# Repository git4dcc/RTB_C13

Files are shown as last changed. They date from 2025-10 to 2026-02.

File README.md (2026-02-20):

# RTB_C13





My homebrew RTB C13 track sensor features a 4 channel RailCom® detector, real-time block occupancy monitoring, and dedicated short-circuit protection. It also includes a built-in EDG bus interface, allowing for seamless accessory fan-out and expanded system integration.

<details>
<summary>See also</summary>

- [RTB_C10 - Master](/../../../../git4dcc/RTB_C10)
- [RTB_C11 - Power](/../../../../git4dcc/RTB_C11)
- [RTB_C12 - Booster](/../../../../git4dcc/RTB_C12)

</details>

<details>
<summary>User Guides</summary>

- User Guide - DE
- [User Guide - EN](https://rtb4dcc.de/rtb_user_guide_en/)

</details>

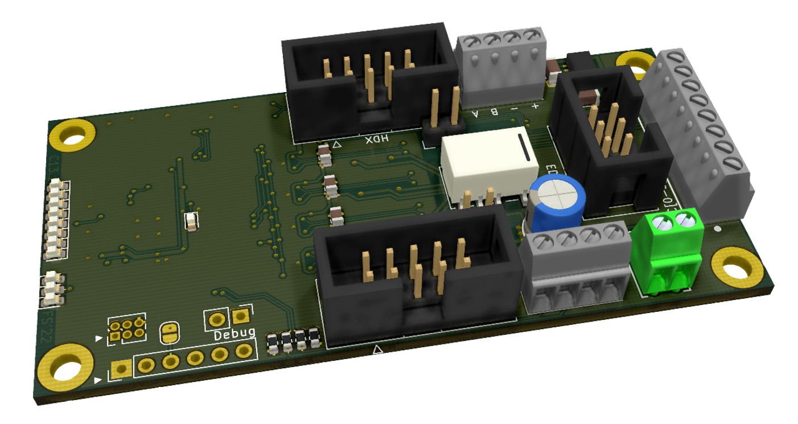
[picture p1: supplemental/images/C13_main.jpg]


## Track Sensor features
- **HDX**
  - HDX bus (2Mbps half duplex, RS-485 differential)
- **EDG**
  - EDG accessory bus bridge (2Mbps half duplex, TTL level)
- **DCC**
  - Quad-Channel Real-time RailCom® Monitoring and Block Occupancy detection.
  - Current measurement per channel
  - Short-circuit safeguarding for all 4 channels
- **Railcom Detector**
  - channel 1 / channel 2
  - detects unlimited number of decoder per track
  - real-time reporting
- **Current Sensor**
  - 1mA current sensitivity
- firmware update over the bus

# Hardware
The PCB layout uses SMD footprints with 0.4mm pitch, 0603 parts down to 0402. Reflow soldering is mandatory.
The PCB has been optimized for automated assembly (SMD parts are located on bottom side).

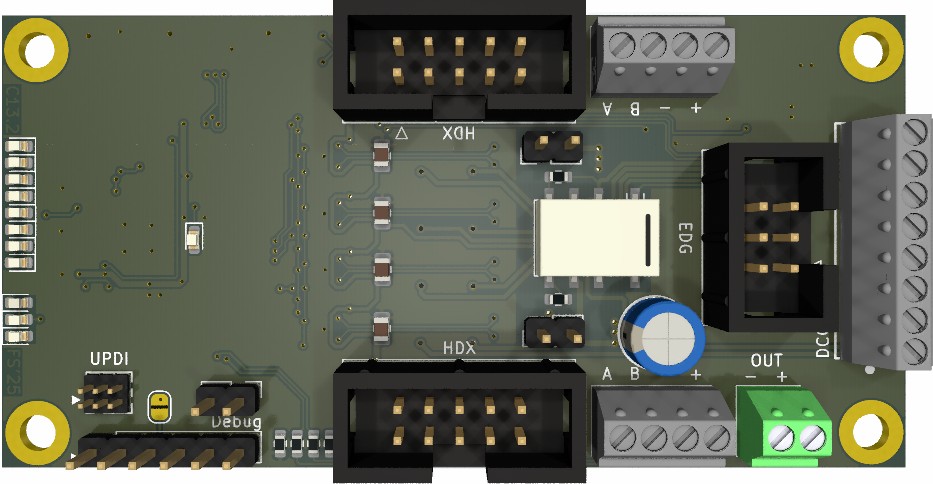
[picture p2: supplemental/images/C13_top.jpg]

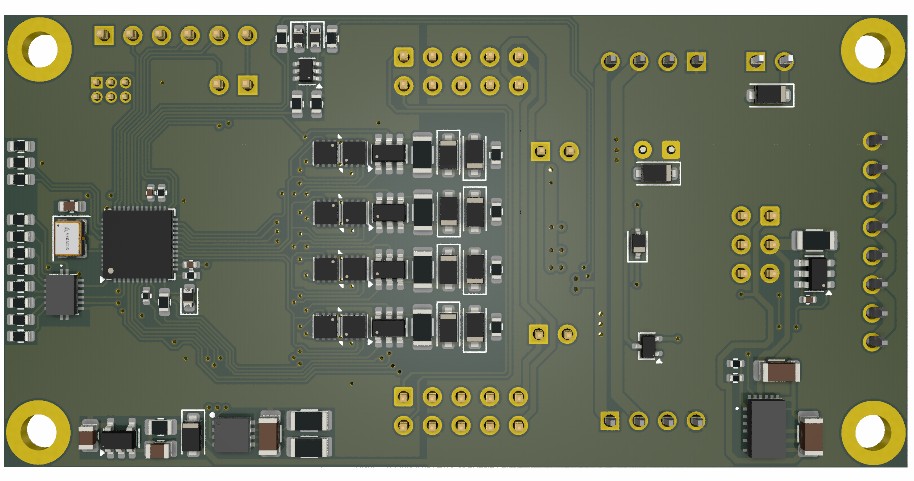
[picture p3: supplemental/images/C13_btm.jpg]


## PCB
- 2-layer PCB, FR4, 1.6mm
- CPU: AVR64DB48

## Kicad
[Schematic](doc/C13_schematic.pdf) | [Layout](doc/C13_layout.pdf) | [Gerber](gerber)

# Firmware
Filename structure: { **pcb** }{ **code** }{ **version** }.hex

Example: **C13F0001**.hex

| | Description |
| --- | --- |
| **pcb** | Name of matching hardware (**C13**) |
| **code** | Type of code contained (**R**=rom, **B**=bootloader, **F**=flash, **U**=bld update, **P**=UPDI factory code) |
| **version** | Release version (**####**) |

[Firmware files](firmware)

## UPDI / Fuses
The fuse settings as well as the P-code (C13Pxxxx.hex) has to be installed by using UPDI.<br>

| Fuses Setting |
| --- |
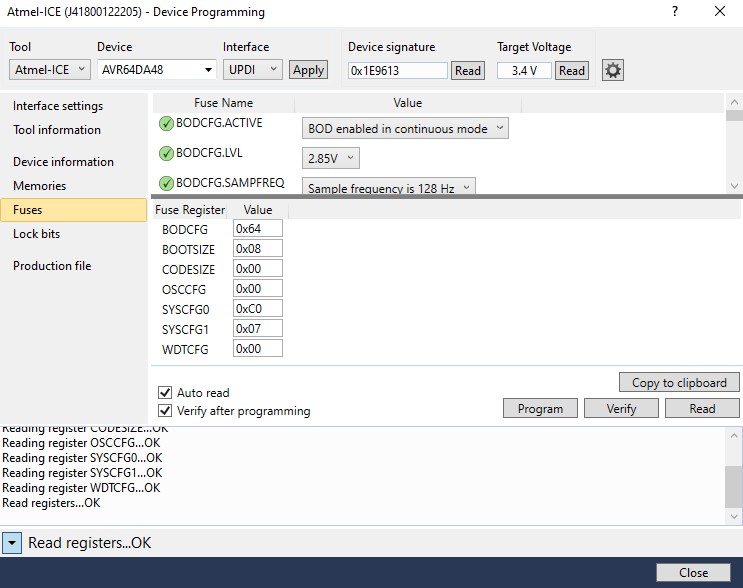
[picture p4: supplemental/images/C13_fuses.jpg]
||

# Images
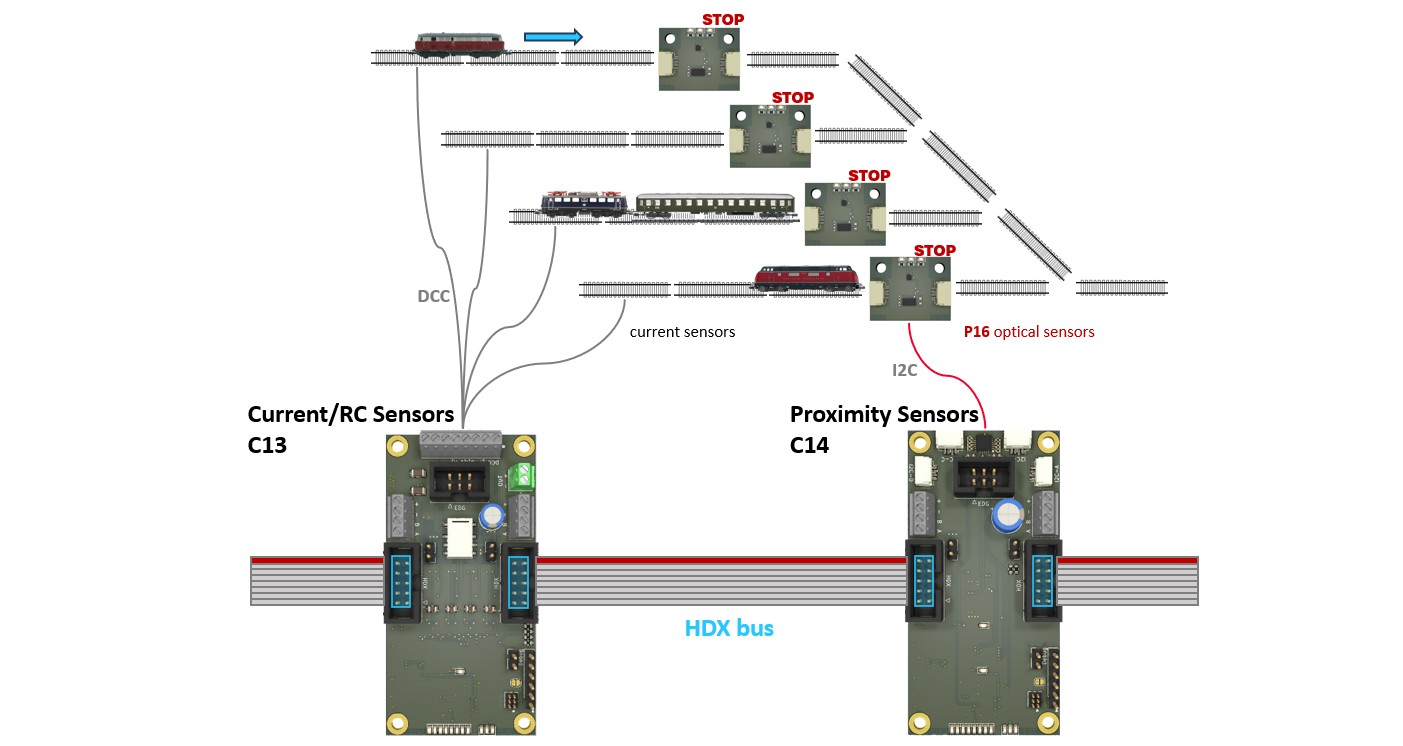
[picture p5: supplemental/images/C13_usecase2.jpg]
 

This project is intended for hobby use only and is distributed in accordance with the Apache License 2.0 agreement.

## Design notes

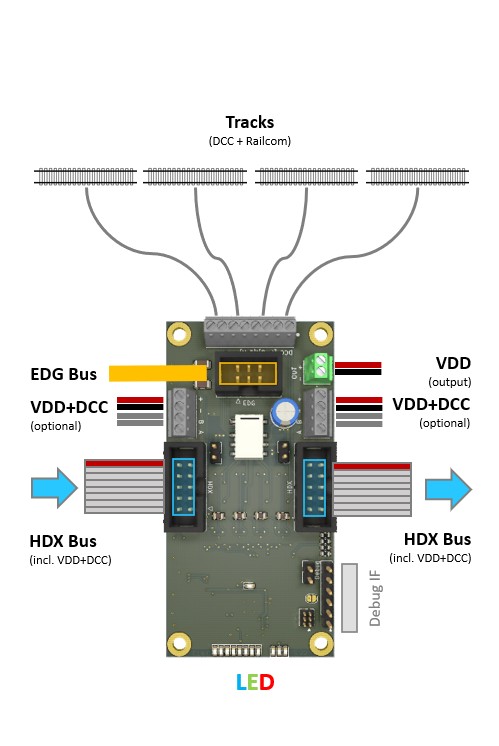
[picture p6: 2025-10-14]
supplemental/images/C13_usecase1.jpg

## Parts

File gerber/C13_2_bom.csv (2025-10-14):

Designator | Qty | Value | Exclude from BOM | Footprint | LCSC Part #
C.0.0,C.0.1 | 2 | FDX daisy chain | Excluded from BOM | Connector_IDC:IDC-Header_2x05_P2.54mm_Vertical
C5 | 1 | 100u/25V | Excluded from BOM | Capacitor_THT:CP_Radial_D6.3mm_P2.50mm
D2,D3 | 2 | LED(grn) | Excluded from BOM | LED_SMD:LED_0603_1608Metric
D5 | 1 | LED(blu) | Excluded from BOM | LED_SMD:LED_0603_1608Metric
D6 | 1 | LED(red) | Excluded from BOM | LED_SMD:LED_0603_1608Metric
D7,D8,D9,D10,D11,D12,D13,D14 | 8 | LED(wht) | Excluded from BOM | LED_SMD:LED_0603_1608Metric
H1,H2,H5,H7 | 4 | MountingHole | Excluded from BOM | MountingHole:MountingHole_3.2mm_M3_ISO7380_Pad
J1 | 1 | V24 | Excluded from BOM | Connector_PinHeader_2.54mm:PinHeader_1x06_P2.54mm_Vertical
J2 | 1 | DCC connector | Excluded from BOM | RTB:1725711
J3 | 1 | EDG connector | Excluded from BOM | Connector_IDC:IDC-Header_2x03_P2.54mm_Vertical
J4,J6 | 2 | Power Daisy Chain | Excluded from BOM | RTB:1725672
J5 | 1 | UDPI | Excluded from BOM | Connector_PinHeader_1.27mm:PinHeader_2x03_P1.27mm_Vertical
J7 | 1 | Power Output | Excluded from BOM | RTB:1725656
JP1 | 1 | SolderJumper_2_Open | Excluded from BOM | Jumper:SolderJumper-2_P1.3mm_Open_RoundedPad1.0x1.5mm
JP2,JP3,JP4 | 3 | Jumper_2_Open | Excluded from BOM | Connector_PinHeader_2.54mm:PinHeader_1x02_P2.54mm_Vertical
K1 | 1 | G6K-2 | Excluded from BOM | Relay_SMD:Relay_DPDT_Omron_G6K-2F-Y
U4 | 1 | 78M05 | Excluded from BOM | Package_TO_SOT_SMD:TO-252-2
C10 | 1 | 100n |  | Capacitor_SMD:C_0402_1005Metric | C1525
R31,R32 | 2 | 2.2k |  | Resistor_SMD:R_0603_1608Metric | C4190
R24,R26 | 2 | 1k |  | Resistor_SMD:R_0402_1005Metric | C11702
C7 | 1 | 22u/10V |  | Capacitor_SMD:C_1206_3216Metric | C12891
C8 | 1 | 10u/25V |  | Capacitor_SMD:C_1206_3216Metric | C13585
C11 | 1 | 100n |  | Capacitor_SMD:C_0603_1608Metric | C14663
R1 | 1 | 160 |  | Resistor_SMD:R_0805_2012Metric | C17471
R78,R79 | 2 | 100 |  | Resistor_SMD:R_1206_3216Metric | C17901
R20 | 1 | 160 |  | Resistor_SMD:R_0603_1608Metric | C22808
R34,R35 | 2 | 220k |  | Resistor_SMD:R_0603_1608Metric | C22961
R5,R6,R28,R72 | 4 | 3.3k |  | Resistor_SMD:R_0603_1608Metric | C22978
R9,R10,R11,R12,R13,R14,R15,R16 | 8 | 4.7k |  | Resistor_SMD:R_0603_1608Metric | C23162
R36,R37 | 2 | 9.1k |  | Resistor_SMD:R_0603_1608Metric | C23260
R3,R18,R21,R23,R27 | 5 | 22 |  | Resistor_SMD:R_0603_1608Metric | C23345
R30 | 1 | 13k |  | Resistor_SMD:R_0402_1005Metric | C25754
R7,R8 | 2 | 100k |  | Resistor_SMD:R_0603_1608Metric | C25803
R4 | 1 | 3.3k |  | Resistor_SMD:R_0402_1005Metric | C25890
C1,C2,C3,C4 | 4 | 1u |  | Capacitor_SMD:C_0805_2012Metric | C28323
R29 | 1 | 68k |  | Resistor_SMD:R_0402_1005Metric | C36871
C12 | 1 | 22u/6.3V |  | Capacitor_SMD:C_0805_2012Metric | C45783
C26 | 1 | 2.2u |  | Capacitor_SMD:C_1206_3216Metric | C50254
D1,D4,D15,D16,D17,D18,D19,D20,D21,D23,D24 | 11 | SS34FA |  | Diode_SMD:D_SOD-123F | C84632
U2 | 1 | MIC5235-3.3 |  | Package_TO_SOT_SMD:SOT-23-5 | C89886
D25,D30,D31 | 3 | Schottky |  | Diode_SMD:D_0603_1608Metric | C153761
Q3 | 1 | BC857BS |  | Package_TO_SOT_SMD:SOT-363_SC-70-6 | C156320
R2,R17,R19,R22 | 4 | 0.1 |  | Resistor_SMD:R_1206_3216Metric | C188071
D22 | 1 | D_Small |  | Diode_SMD:D_SOD-323 | C191023
C6,C13 | 2 | 100n |  | Capacitor_SMD:C_0402_1005Metric | C307331
R25 | 1 | 0.01 |  | Resistor_SMD:R_1206_3216Metric | C308574
C27 | 1 | 10u/25V |  | Capacitor_SMD:C_0805_2012Metric | C440198
U5,U6,U8,U9,U11,U12,U14,U15 | 8 | INA381 |  | Package_SON:WSON-8-1EP_2x2mm_P0.5mm_EP0.9x1.6mm | C544574
IC1 | 1 | 74HC595BQ,115 |  | 74HC595BQ115 | C547123
Q1 | 1 | BC848 |  | Package_TO_SOT_SMD:SOT-323_SC-70 | C600677
IC9 | 1 | THVD1450DRBR |  | RTB:SON65P300X300X100-9N-D | C1850226
X1 | 1 | ASE-xxxMHz |  | Oscillator:Oscillator_SMD_Abracon_ASE-4Pin_3.2x2.5mm | C1987527
U16 | 1 | INA181-A4 |  | Package_TO_SOT_SMD:SOT-23-6 | C2058842
U3,U7,U10,U13 | 4 | INA181-A1 |  | Package_TO_SOT_SMD:SOT-23-6 | C2058943
U1 | 1 | AVR-64DA48 |  | Package_DFN_QFN:UQFN-48-1EP_6x6mm_P0.4mm_EP4.62x4.62mm | C3227372
IC2 | 1 | MPM3610AGQV |  | RTB:MPM3610AGQVP | C5173872

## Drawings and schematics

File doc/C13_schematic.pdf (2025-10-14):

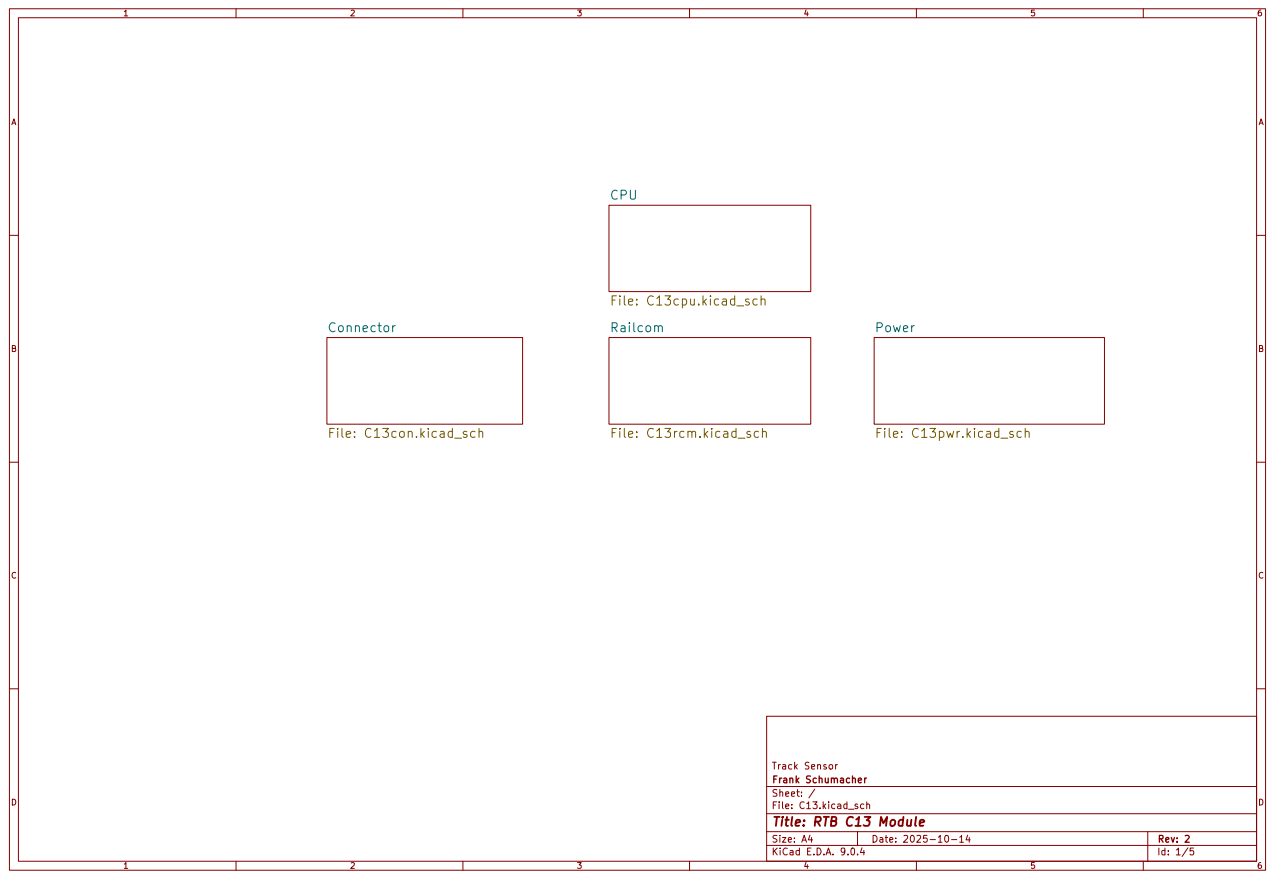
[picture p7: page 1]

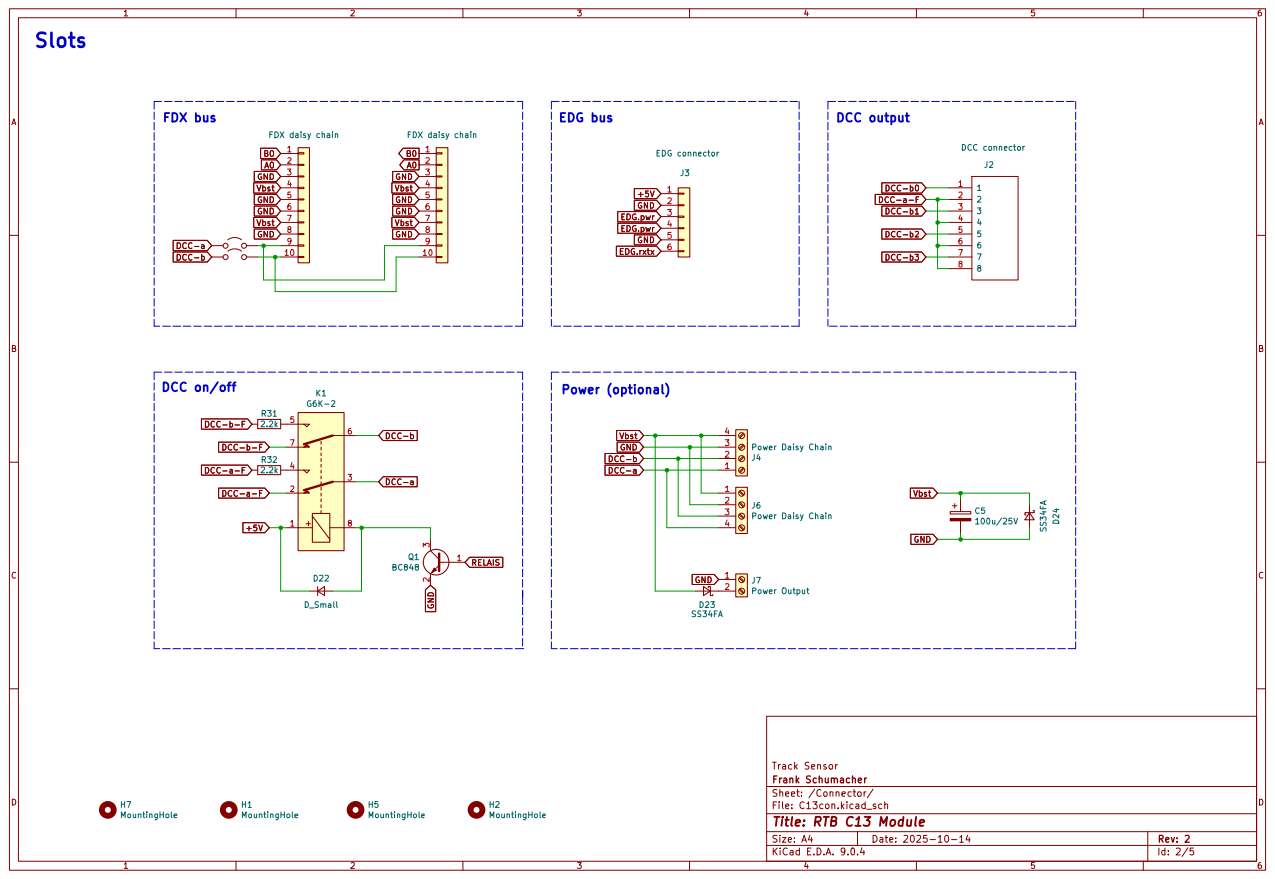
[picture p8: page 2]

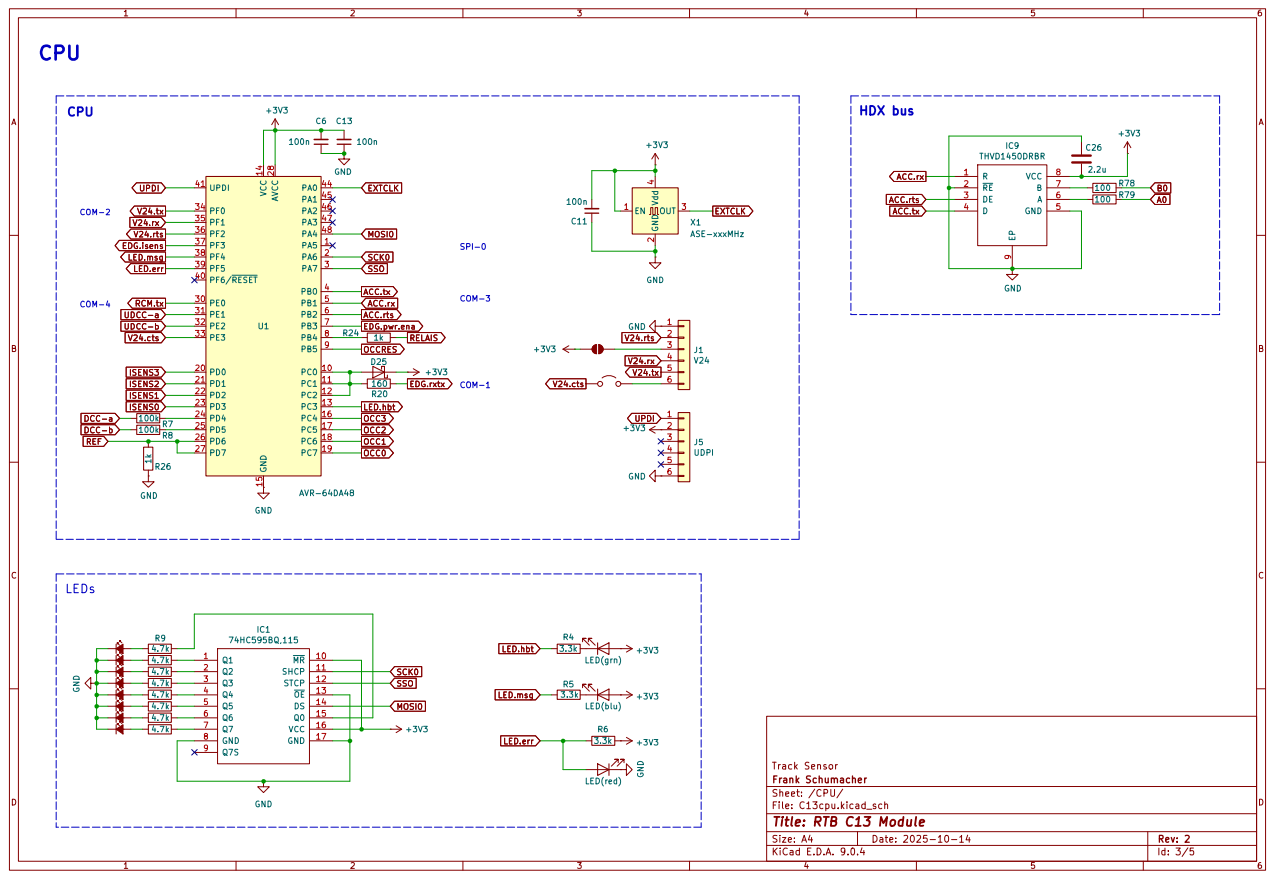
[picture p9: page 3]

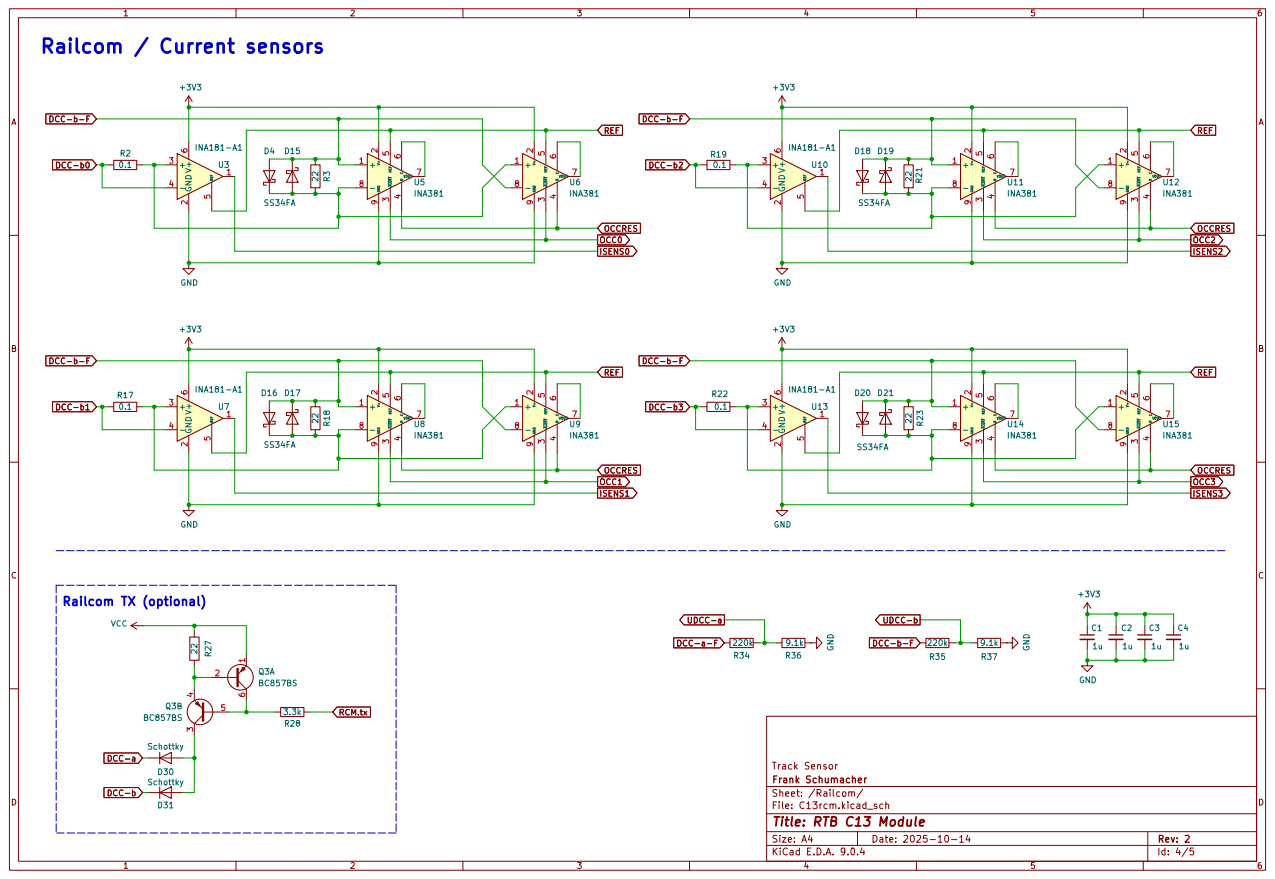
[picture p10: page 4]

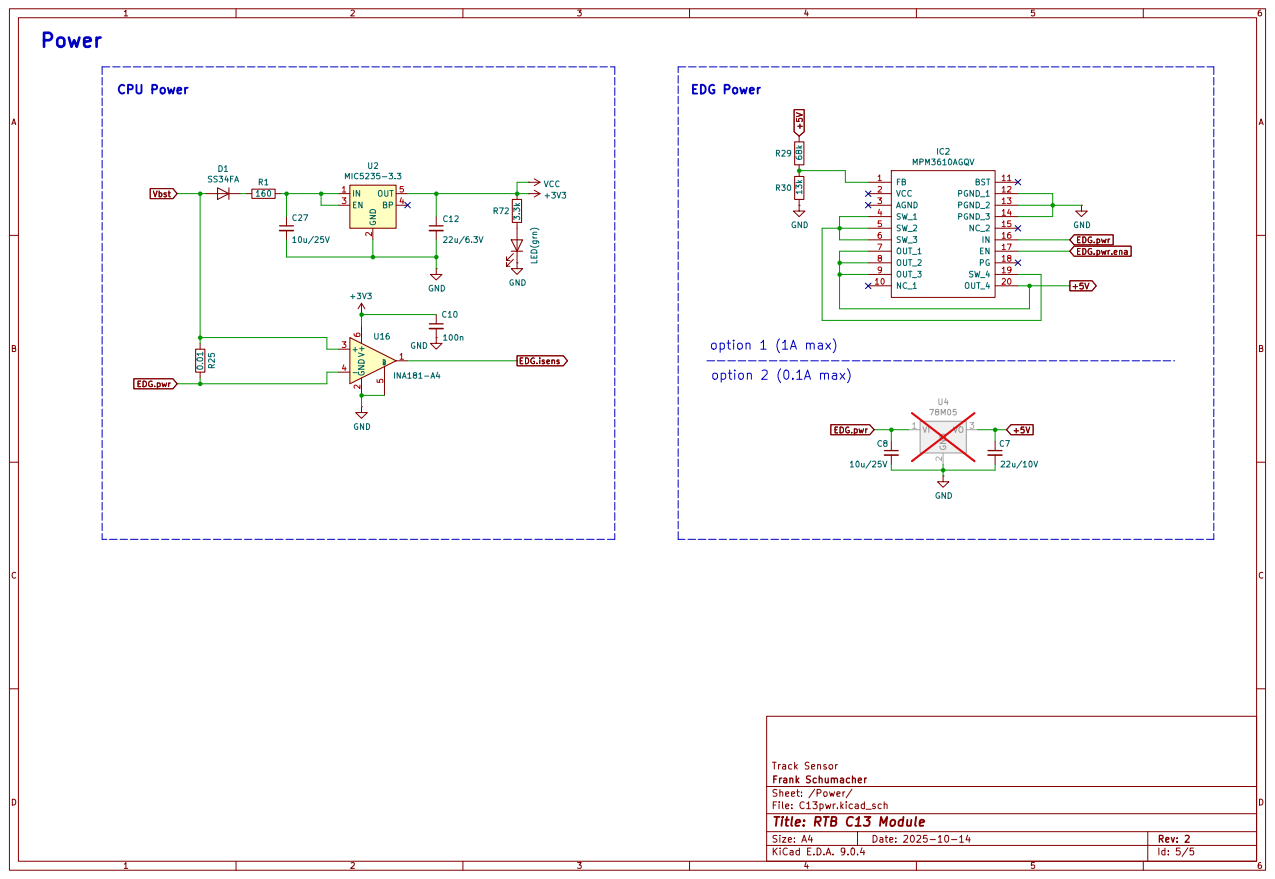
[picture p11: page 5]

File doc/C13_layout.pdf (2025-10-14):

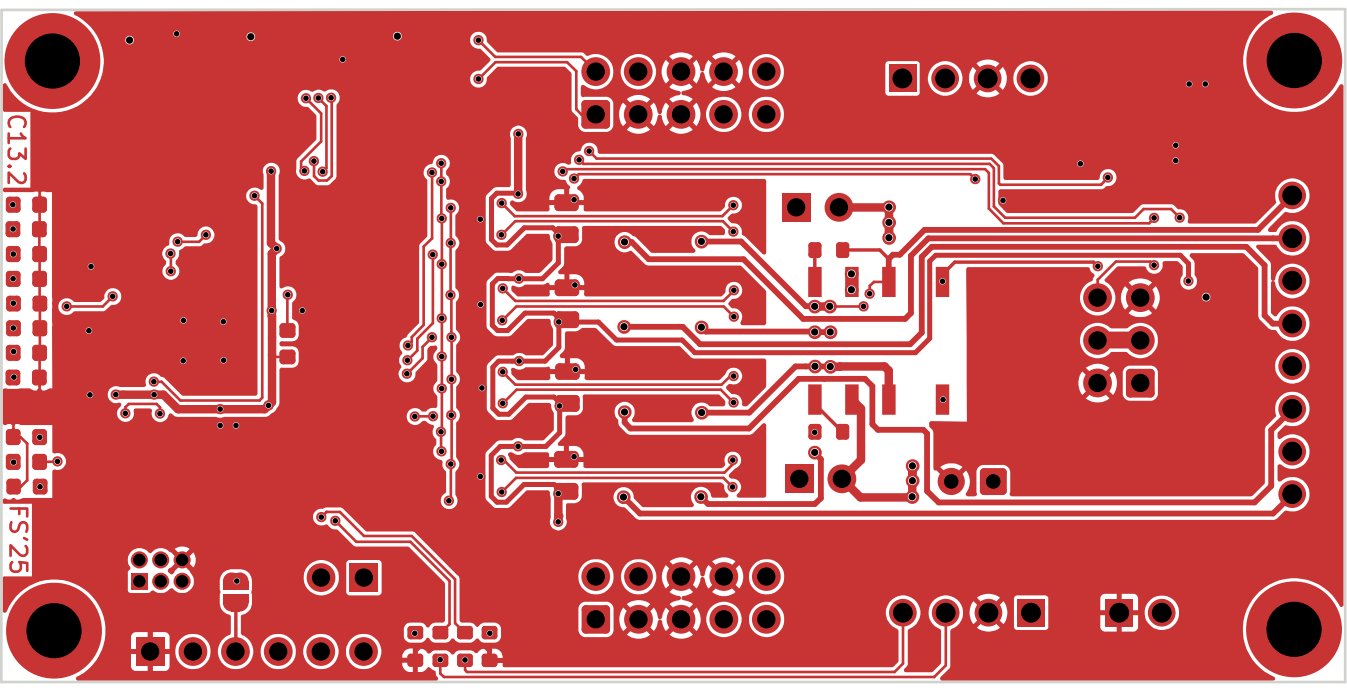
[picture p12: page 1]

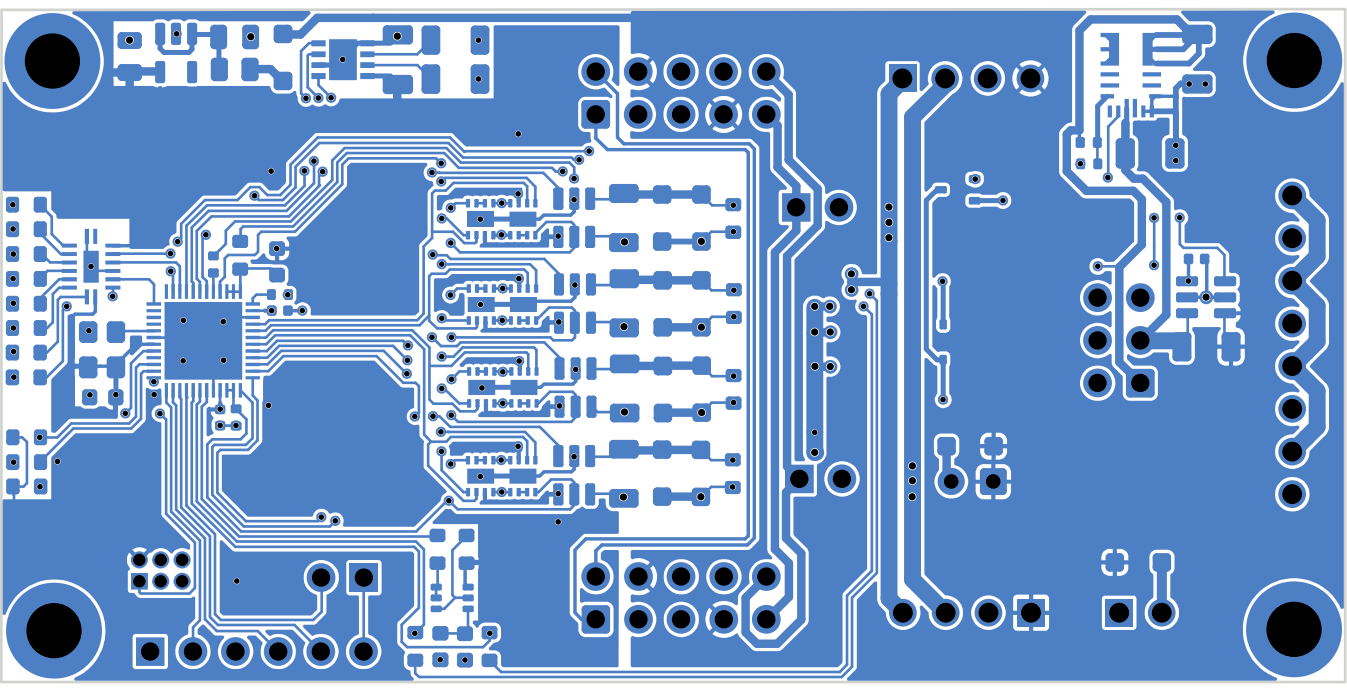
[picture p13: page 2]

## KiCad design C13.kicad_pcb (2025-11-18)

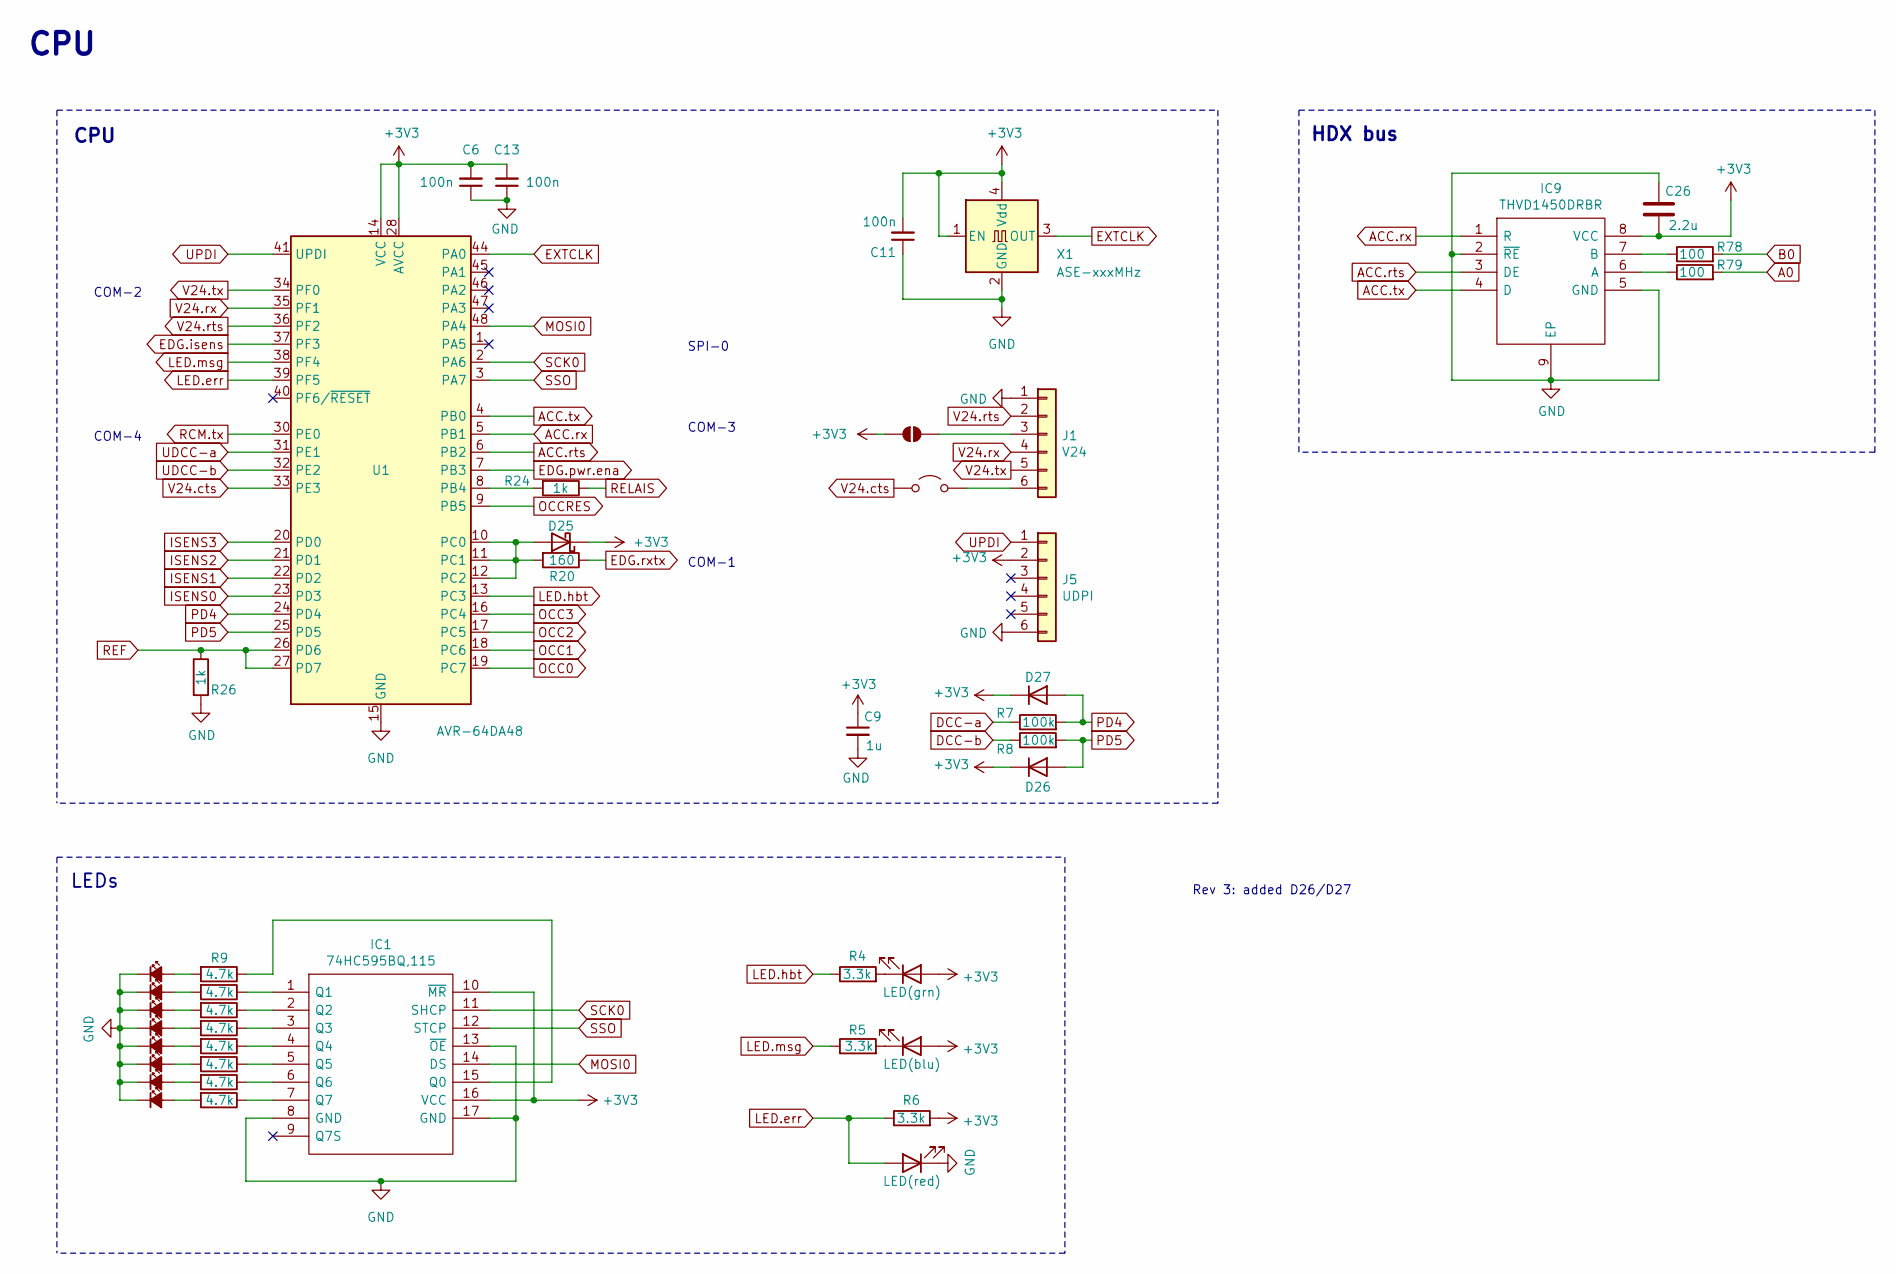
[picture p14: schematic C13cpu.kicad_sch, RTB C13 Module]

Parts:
C6, C13: 100n; C_0402_1005Metric; LCSC Part # C307331
C9: 1u; C_0805_2012Metric; LCSC Part # C28323
C11: 100n; C_0603_1608Metric; LCSC Part # C14663
C26: 2.2u; C_1206_3216Metric; LCSC Part # C50254
D3: LED(grn); LED_0603_1608Metric
D5: LED(blu); LED_0603_1608Metric
D6: LED(red); LED_0603_1608Metric
D7, D8, D9, D10, D11, D12, D13, D14: LED(wht); LED_0603_1608Metric
D25, D26, D27: Schottky; D_0603_1608Metric; LCSC Part # C153761
IC1: 74HC595BQ,115; 74HC595BQ115; Mouser Part Number 771-74HC595BQ-G; LCSC Part # C547123
IC9: THVD1450DRBR; SON65P300X300X100-9N-D; LCSC Part # C1850226
J1: V24; PinHeader_1x06_P2.54mm_Vertical
J5: UDPI; PinHeader_2x03_P1.27mm_Vertical
JP1: SolderJumper_2_Open; SolderJumper-2_P1.3mm_Open_RoundedPad1.0x1.5mm
JP2: Jumper_2_Open; PinHeader_1x02_P2.54mm_Vertical
R4: 3.3k; R_0402_1005Metric; LCSC Part # C25890
R5, R6: 3.3k; R_0603_1608Metric; LCSC Part # C22978
R7, R8: 100k; R_0603_1608Metric; LCSC Part # C25803
R9, R10, R11, R12, R13, R14, R15, R16: 4.7k; R_0603_1608Metric; LCSC Part # C23162
R20: 160; R_0603_1608Metric; LCSC Part # C22808
R24, R26: 1k; R_0402_1005Metric; LCSC Part # C11702
R78, R79: 100; R_1206_3216Metric; LCSC Part # C17901
U1: AVR-64DA48; UQFN-48-1EP_6x6mm_P0.4mm_EP4.62x4.62mm; LCSC Part # C3227372
X1: ASE-xxxMHz; Oscillator_SMD_Abracon_ASE-4Pin_3.2x2.5mm; LCSC Part # C1987527

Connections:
+3V3: C6.2, C9.1, C11.2, C13.2, C26.2, D3.2 (A), D5.2 (A), D25.1 (K), D26.1 (K), D27.1 (K), IC1.10 (~MR), IC1.16 (VCC), IC9.8 (VCC), J5.2, JP1.2 (B), R6.2, U1.14 (VCC), U1.28 (AVCC), U1.42 (VCC), X1.1 (EN), X1.4 (Vdd); also elsewhere on the board
A0: R79.2; also elsewhere on the board
ACC.rts: IC9.3 (DE), U1.6 (PB2)
ACC.rx: IC9.1 (R), U1.5 (PB1)
ACC.tx: IC9.4 (D), U1.4 (PB0)
B0: R78.2; also elsewhere on the board
DCC-a: R7.1; also elsewhere on the board
DCC-b: R8.1; also elsewhere on the board
EDG.isens: U1.37 (PF3); also elsewhere on the board
EDG.pwr.ena: U1.7 (PB3); also elsewhere on the board
EDG.rxtx: R20.1; also elsewhere on the board
EXTCLK: U1.44 (PA0), X1.3 (OUT)
GND: C6.1, C9.2, C11.1, C13.1, C26.1, D6.1 (K), D7.1 (K), D8.1 (K), D9.1 (K), D10.1 (K), D11.1 (K), D12.1 (K), D13.1 (K), D14.1 (K), IC1.8 (GND), IC1.13 (~OE), IC1.17 (GND), IC9.2 (~RE), IC9.5 (GND), IC9.9 (EP), J1.1, J5.6, R26.2, U1.15 (GND), U1.29 (GND), U1.43 (GND), U1.49 (GND), X1.2 (GND); also elsewhere on the board
ISENS0: U1.23 (PD3); also elsewhere on the board
ISENS1: U1.22 (PD2); also elsewhere on the board
ISENS2: U1.21 (PD1); also elsewhere on the board
ISENS3: U1.20 (PD0); also elsewhere on the board
LED.err: D6.2 (A), R6.1, U1.39 (PF5)
LED.hbt: R4.1, U1.13 (PC3)
LED.msg: R5.1, U1.38 (PF4)
MOSI0: IC1.14 (DS), U1.48 (PA4)
unnamed: D3.1 (K), R4.2
unnamed: D5.1 (K), R5.2
unnamed: D7.2 (A), R16.2
unnamed: D8.2 (A), R15.2
unnamed: D9.2 (A), R14.2
unnamed: D10.2 (A), R13.2
unnamed: D11.2 (A), R12.2
unnamed: D12.2 (A), R11.2
unnamed: D13.2 (A), R10.2
unnamed: D14.2 (A), R9.2
unnamed: D25.2 (A), R20.2, U1.10 (PC0), U1.11 (PC1), U1.12 (PC2)
unnamed: IC1.15 (Q0), R9.1
unnamed: IC1.1 (Q1), R10.1
unnamed: IC1.2 (Q2), R11.1
unnamed: IC1.3 (Q3), R12.1
unnamed: IC1.4 (Q4), R13.1
unnamed: IC1.5 (Q5), R14.1
unnamed: IC1.6 (Q6), R15.1
unnamed: IC1.7 (Q7), R16.1
unnamed: IC9.6 (A), R79.1
unnamed: IC9.7 (B), R78.1
unnamed: J1.3, JP1.1 (A)
unnamed: J1.6, JP2.1 (A)
unnamed: R24.2, U1.8 (PB4)
OCC0: U1.19 (PC7); also elsewhere on the board
OCC1: U1.18 (PC6); also elsewhere on the board
OCC2: U1.17 (PC5); also elsewhere on the board
OCC3: U1.16 (PC4); also elsewhere on the board
OCCRES: U1.9 (PB5); also elsewhere on the board
PD4: D27.2 (A), R7.2, U1.24 (PD4)
PD5: D26.2 (A), R8.2, U1.25 (PD5)
RCM.tx: U1.30 (PE0); also elsewhere on the board
REF: R26.1, U1.26 (PD6), U1.27 (PD7); also elsewhere on the board
RELAIS: R24.1; also elsewhere on the board
SCK0: IC1.11 (SHCP), U1.2 (PA6)
SSO: IC1.12 (STCP), U1.3 (PA7)
UDCC-a: U1.31 (PE1); also elsewhere on the board
UDCC-b: U1.32 (PE2); also elsewhere on the board
UPDI: J5.1, U1.41 (UPDI)
V24.cts: JP2.2 (B), U1.33 (PE3)
V24.rts: J1.2, U1.36 (PF2)
V24.rx: J1.4, U1.35 (PF1)
V24.tx: J1.5, U1.34 (PF0)

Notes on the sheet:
COM-4
COM-1
Rev 3: added D26/D27
COM-3
CPU
COM-2
LEDs
SPI-0
HDX bus

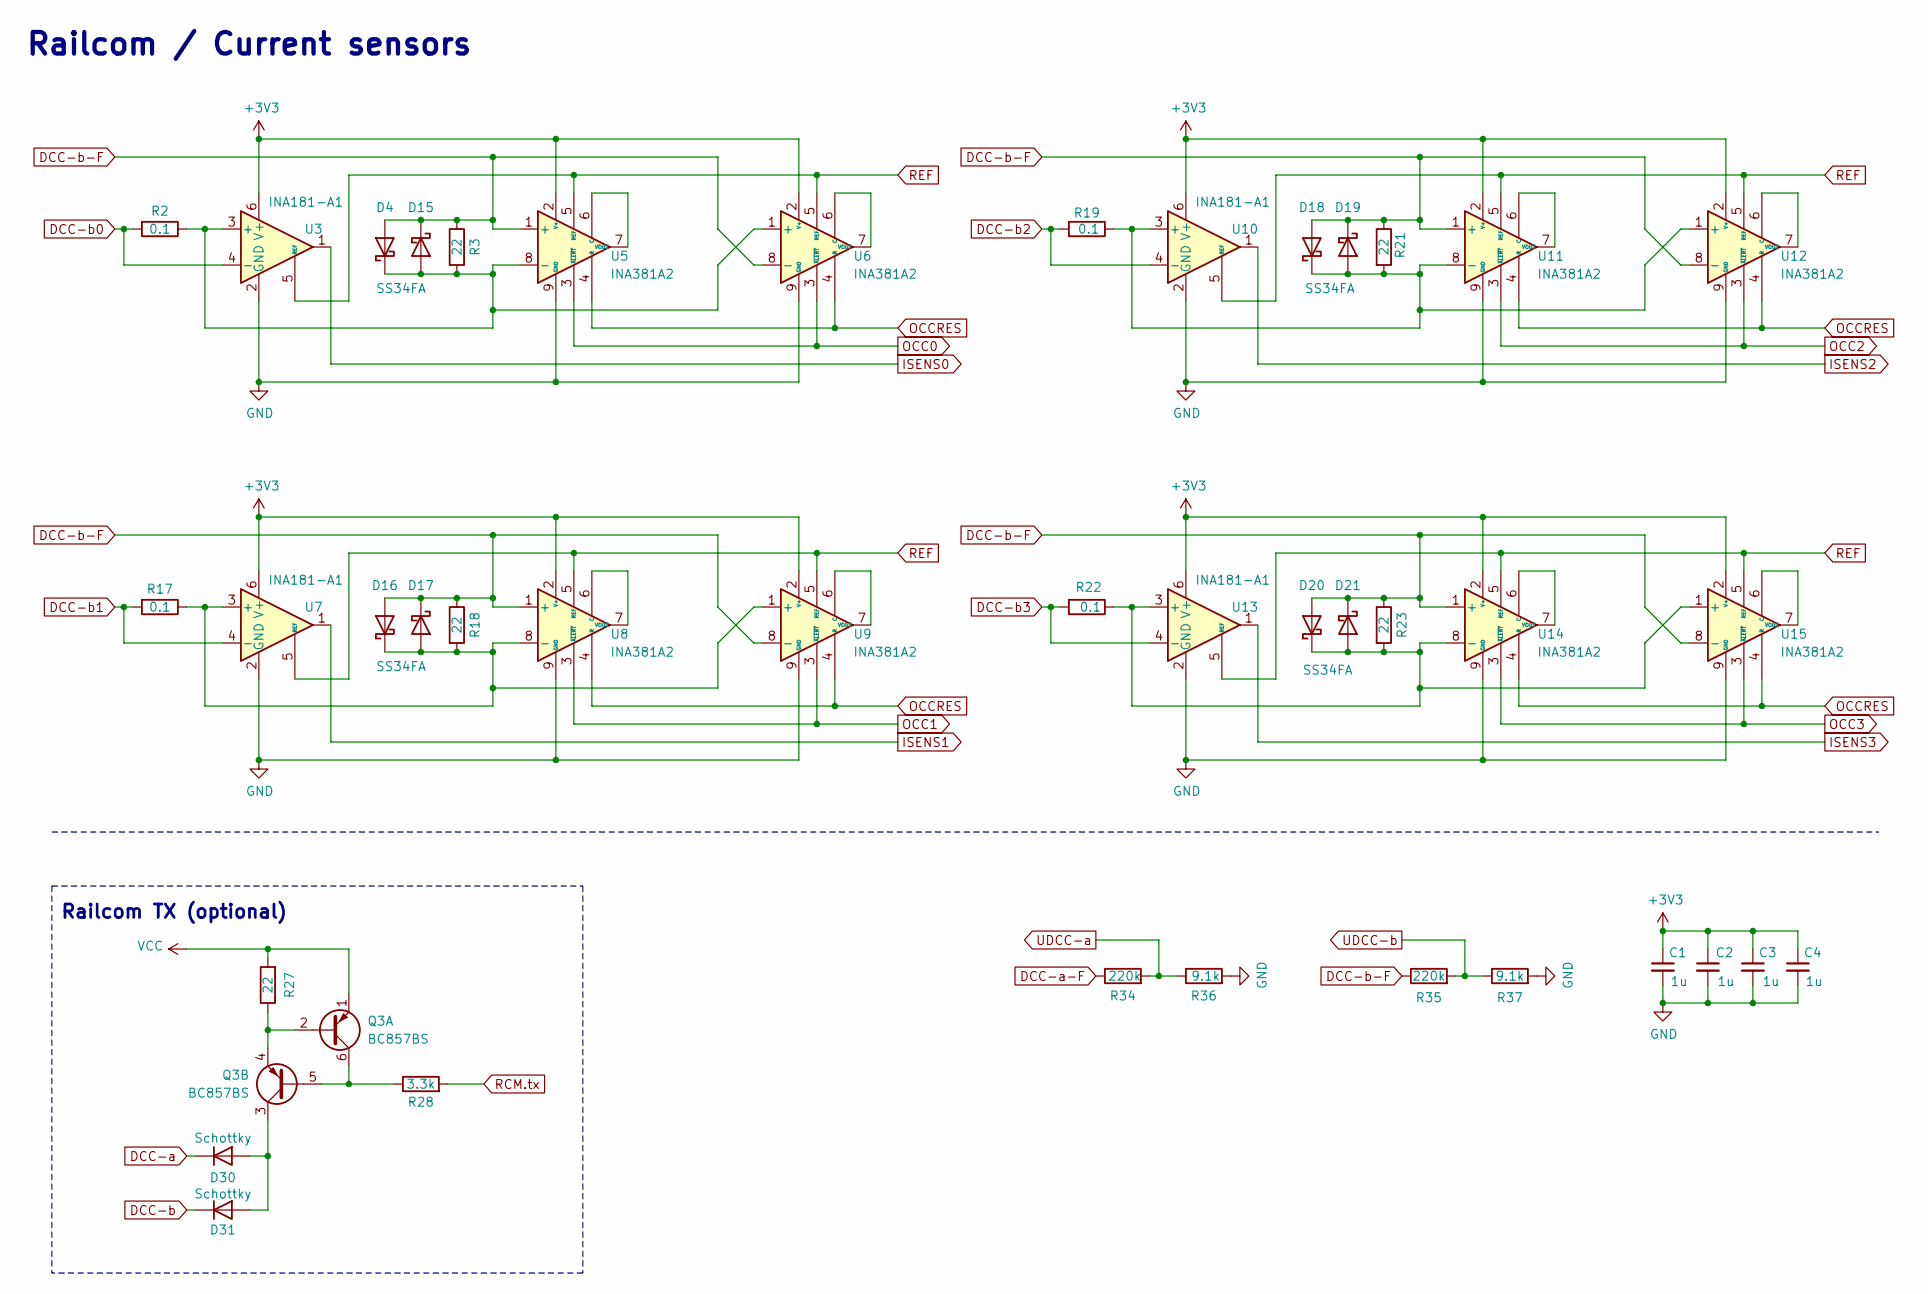
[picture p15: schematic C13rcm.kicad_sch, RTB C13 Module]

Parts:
C1, C2, C3, C4: 1u; C_0805_2012Metric; LCSC Part # C28323
D4, D15, D16, D17, D18, D19, D20, D21: SS34FA; D_SOD-123F; LCSC Part # C84632
D30, D31: Schottky; D_0603_1608Metric; LCSC Part # C153761
Q3: BC857BS; SOT-363_SC-70-6; LCSC Part # C156320
R2, R17, R19, R22: 0.1; R_1206_3216Metric; LCSC Part # C188071
R3, R18, R21, R23, R27: 22; R_0603_1608Metric; LCSC Part # C23345
R28: 3.3k; R_0603_1608Metric; LCSC Part # C22978
R34, R35: 220k; R_0603_1608Metric; LCSC Part # C22961
R36, R37: 9.1k; R_0603_1608Metric; LCSC Part # C23260
U3, U7, U10, U13: INA181-A1; SOT-23-6; LCSC Part # C2058943
U5, U6, U8, U9, U11, U12, U14, U15: INA381A2; WSON-8-1EP_2x2mm_P0.5mm_EP0.9x1.6mm; LCSC Part # C2155688

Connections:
+3V3: C1.1, C2.1, C3.1, C4.1, Q3.1 (E1), R27.2, U3.6 (V+), U5.2 (V+), U6.2 (V+), U7.6 (V+), U8.2 (V+), U9.2 (V+), U10.6 (V+), U11.2 (V+), U12.2 (V+), U13.6 (V+), U14.2 (V+), U15.2 (V+); also elsewhere on the board
DCC-a: D30.1 (K); also elsewhere on the board
DCC-a-F: R34.1; also elsewhere on the board
DCC-b: D31.1 (K); also elsewhere on the board
DCC-b0: R2.2, U3.4 (-); also elsewhere on the board
DCC-b1: R17.2, U7.4 (-); also elsewhere on the board
DCC-b2: R19.2, U10.4 (-); also elsewhere on the board
DCC-b3: R22.2, U13.4 (-); also elsewhere on the board
DCC-b-F: D4.2 (A), D15.1 (K), D16.2 (A), D17.1 (K), D18.2 (A), D19.1 (K), D20.2 (A), D21.1 (K), R3.1, R18.1, R21.1, R23.1, R35.1, U5.1 (+), U6.8 (-), U8.1 (+), U9.8 (-), U11.1 (+), U12.8 (-), U14.1 (+), U15.8 (-); also elsewhere on the board
GND: C1.2, C2.2, C3.2, C4.2, R36.2, R37.2, U3.2 (GND), U5.9 (GND), U6.9 (GND), U7.2 (GND), U8.9 (GND), U9.9 (GND), U10.2 (GND), U11.9 (GND), U12.9 (GND), U13.2 (GND), U14.9 (GND), U15.9 (GND); also elsewhere on the board
ISENS0: U3.1; also elsewhere on the board
ISENS1: U7.1; also elsewhere on the board
ISENS2: U10.1; also elsewhere on the board
ISENS3: U13.1; also elsewhere on the board
unnamed: D4.1 (K), D15.2 (A), R2.1, R3.2, U3.3 (+), U5.8 (-), U6.1 (+)
unnamed: D16.1 (K), D17.2 (A), R17.1, R18.2, U7.3 (+), U8.8 (-), U9.1 (+)
unnamed: D18.1 (K), D19.2 (A), R19.1, R21.2, U10.3 (+), U11.8 (-), U12.1 (+)
unnamed: D20.1 (K), D21.2 (A), R22.1, R23.2, U13.3 (+), U14.8 (-), U15.1 (+)
unnamed: D30.2 (A), D31.2 (A), Q3.3 (C2)
unnamed: Q3.2 (B1), Q3.4 (E2), R27.1
unnamed: Q3.5 (B2), Q3.6 (C1), R28.1
unnamed: U5.6 (C), U5.7 (VOUT)
unnamed: U6.6 (C), U6.7 (VOUT)
unnamed: U8.6 (C), U8.7 (VOUT)
unnamed: U9.6 (C), U9.7 (VOUT)
unnamed: U11.6 (C), U11.7 (VOUT)
unnamed: U12.6 (C), U12.7 (VOUT)
unnamed: U14.6 (C), U14.7 (VOUT)
unnamed: U15.6 (C), U15.7 (VOUT)
OCC0: U5.3 (~ALERT), U6.3 (~ALERT); also elsewhere on the board
OCC1: U8.3 (~ALERT), U9.3 (~ALERT); also elsewhere on the board
OCC2: U11.3 (~ALERT), U12.3 (~ALERT); also elsewhere on the board
OCC3: U14.3 (~ALERT), U15.3 (~ALERT); also elsewhere on the board
OCCRES: U5.4 (R), U6.4 (R), U8.4 (R), U9.4 (R), U11.4 (R), U12.4 (R), U14.4 (R), U15.4 (R); also elsewhere on the board
RCM.tx: R28.2; also elsewhere on the board
REF: U3.5 (REF), U5.5 (REF), U6.5 (REF), U7.5 (REF), U8.5 (REF), U9.5 (REF), U10.5 (REF), U11.5 (REF), U12.5 (REF), U13.5 (REF), U14.5 (REF), U15.5 (REF); also elsewhere on the board
UDCC-a: R34.2, R36.1; also elsewhere on the board
UDCC-b: R35.2, R37.1; also elsewhere on the board

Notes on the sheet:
Railcom / Current sensors
Railcom TX (optional)

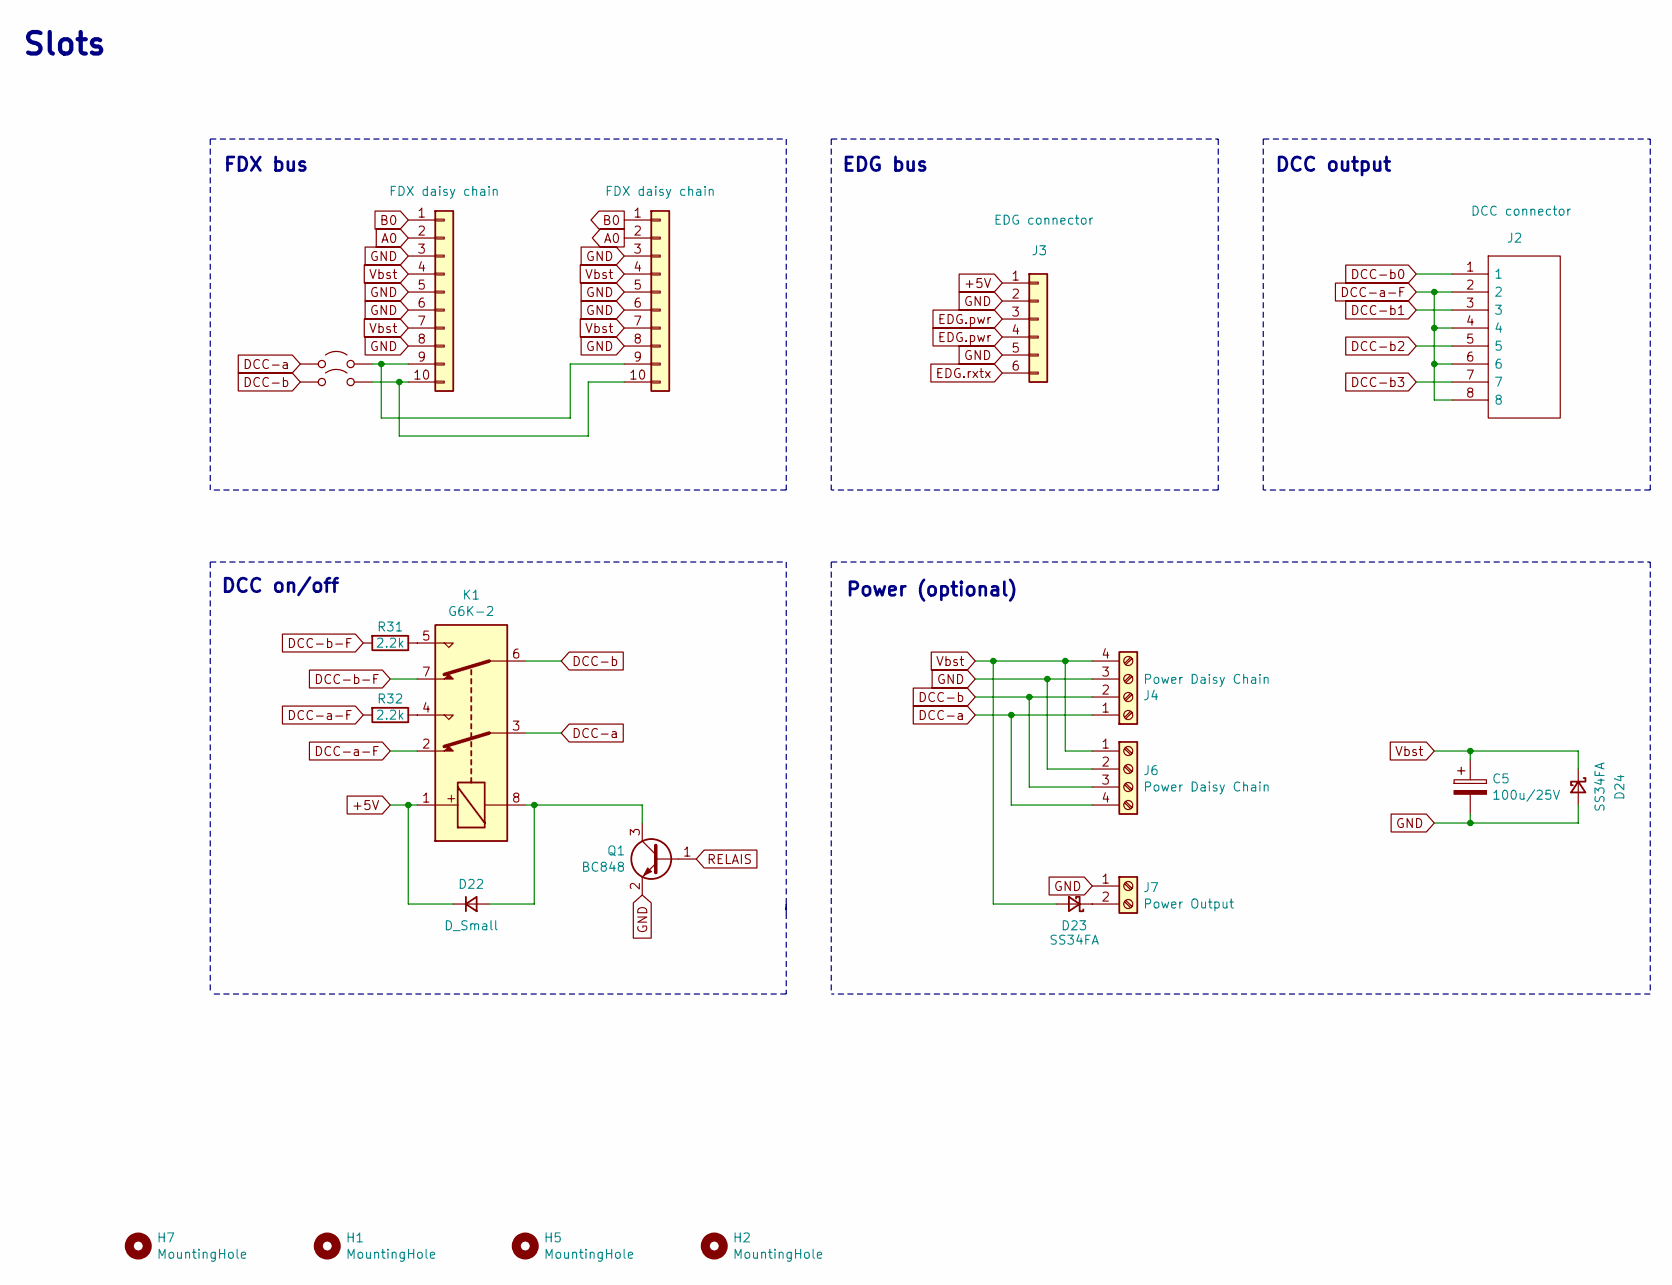
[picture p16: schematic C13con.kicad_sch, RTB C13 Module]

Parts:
C5: 100u/25V; CP_Radial_D6.3mm_P2.50mm
C.0.0, C.0.1: FDX daisy chain; IDC-Header_2x05_P2.54mm_Vertical
D22: D_Small; D_SOD-323; LCSC Part # C191023
D23, D24: SS34FA; D_SOD-123F; LCSC Part # C84632
H1, H2, H5, H7: MountingHole; MountingHole_3.2mm_M3_ISO7380_Pad
J2: DCC connector; 1725711
J3: EDG connector; IDC-Header_2x03_P2.54mm_Vertical
J4, J6: Power Daisy Chain; 1725672
J7: Power Output; 1725656
JP3, JP4: Jumper_2_Open; PinHeader_1x02_P2.54mm_Vertical
K1: G6K-2; Relay_DPDT_Omron_G6K-2F-Y
Q1: BC848; SOT-323_SC-70; LCSC Part # C600677
R31, R32: 2.2k; R_0603_1608Metric; LCSC Part # C4190

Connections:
+5V: D22.1 (K), J3.1, K1.1; also elsewhere on the board
A0: C.0.0.2, C.0.1.2; also elsewhere on the board
B0: C.0.0.1, C.0.1.1; also elsewhere on the board
DCC-a: J4.1, J6.4, JP3.2 (B), K1.3; also elsewhere on the board
DCC-a-F: J2.2, J2.4, J2.6, J2.8, K1.2, R32.2; also elsewhere on the board
DCC-b: J4.2, J6.3, JP4.2 (B), K1.6; also elsewhere on the board
DCC-b0: J2.1; also elsewhere on the board
DCC-b1: J2.3; also elsewhere on the board
DCC-b2: J2.5; also elsewhere on the board
DCC-b3: J2.7; also elsewhere on the board
DCC-b-F: K1.7, R31.2; also elsewhere on the board
EDG.pwr: J3.3, J3.4; also elsewhere on the board
EDG.rxtx: J3.6; also elsewhere on the board
GND: C5.2, C.0.0.3, C.0.0.5, C.0.0.6, C.0.0.8, C.0.1.3, C.0.1.5, C.0.1.6, C.0.1.8, D24.2 (A), J3.2, J3.5, J4.3, J6.2, J7.1, Q1.2 (E); also elsewhere on the board
unnamed: C.0.0.9, C.0.1.9, JP3.1 (A)
unnamed: C.0.0.10, C.0.1.10, JP4.1 (A)
unnamed: D22.2 (A), K1.8, Q1.3 (C)
unnamed: D23.1 (K), J7.2
unnamed: K1.4, R32.1
unnamed: K1.5, R31.1
RELAIS: Q1.1 (B); also elsewhere on the board
Vbst: C5.1, C.0.0.4, C.0.0.7, C.0.1.4, C.0.1.7, D23.2 (A), D24.1 (K), J4.4, J6.1; also elsewhere on the board

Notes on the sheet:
Power (optional)
EDG bus
DCC output
FDX bus
Slots
DCC on/off

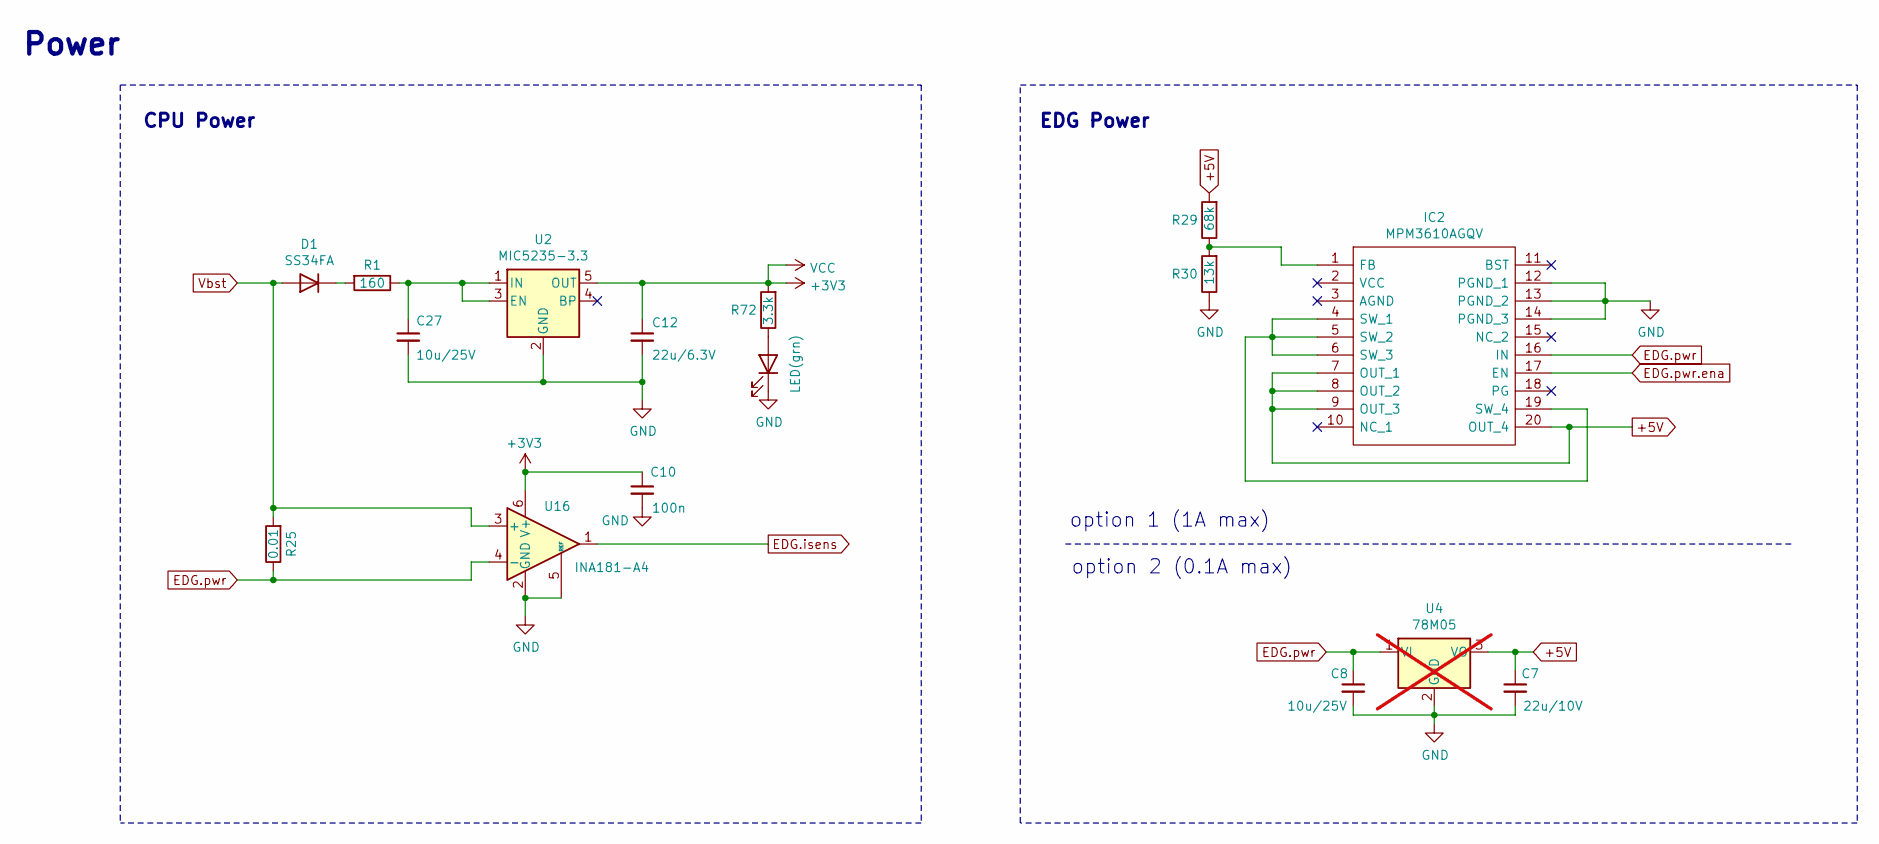
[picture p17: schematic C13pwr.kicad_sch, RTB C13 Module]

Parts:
C7: 22u/10V; C_1206_3216Metric; LCSC Part # C12891
C8: 10u/25V; C_1206_3216Metric; LCSC Part # C13585
C10: 100n; C_0402_1005Metric; LCSC Part # C1525
C12: 22u/6.3V; C_0805_2012Metric; LCSC Part # C45783
C27: 10u/25V; C_0805_2012Metric; LCSC Part # C440198
D1: SS34FA; D_SOD-123F; LCSC Part # C84632
D2: LED(grn); LED_0603_1608Metric
IC2: MPM3610AGQV; MPM3610AGQVP; LCSC Part # C5173872
R1: 160; R_0805_2012Metric; LCSC Part # C17471
R25: 0.01; R_1206_3216Metric; LCSC Part # C308574
R29: 68k; R_0402_1005Metric; LCSC Part # C36871
R30: 13k; R_0402_1005Metric; LCSC Part # C25754
R72: 3.3k; R_0603_1608Metric; LCSC Part # C22978
U2: MIC5235-3.3; SOT-23-5; LCSC Part # C89886
U4: 78M05; TO-252-2; not fitted
U16: INA181-A4; SOT-23-6; LCSC Part # C2058842

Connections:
+3V3: C10.1, C12.1, R72.2, U2.5 (OUT), U16.6 (V+); also elsewhere on the board
+5V: C7.1, IC2.7 (OUT_1), IC2.8 (OUT_2), IC2.9 (OUT_3), IC2.20 (OUT_4), R29.2, U4.3 (VO); also elsewhere on the board
EDG.isens: U16.1; also elsewhere on the board
EDG.pwr: C8.1, IC2.16 (IN), R25.1, U4.1 (VI), U16.4 (-); also elsewhere on the board
EDG.pwr.ena: IC2.17 (EN); also elsewhere on the board
GND: C7.2, C8.2, C10.2, C12.2, C27.2, D2.1 (K), IC2.12 (PGND_1), IC2.13 (PGND_2), IC2.14 (PGND_3), R30.1, U2.2 (GND), U4.2 (GND), U16.2 (GND), U16.5 (REF); also elsewhere on the board
unnamed: D1.1 (K), R1.2
unnamed: D2.2 (A), R72.1
unnamed: IC2.1 (FB), R29.1, R30.2
unnamed: IC2.4 (SW_1), IC2.5 (SW_2), IC2.6 (SW_3), IC2.19 (SW_4)
unnamed: C27.1, R1.1, U2.1 (IN), U2.3 (EN)
Vbst: D1.2 (A), R25.2, U16.3 (+); also elsewhere on the board

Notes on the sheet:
EDG Power
option 1 (1A max)
option 2 (0.1A max)
Power
CPU Power

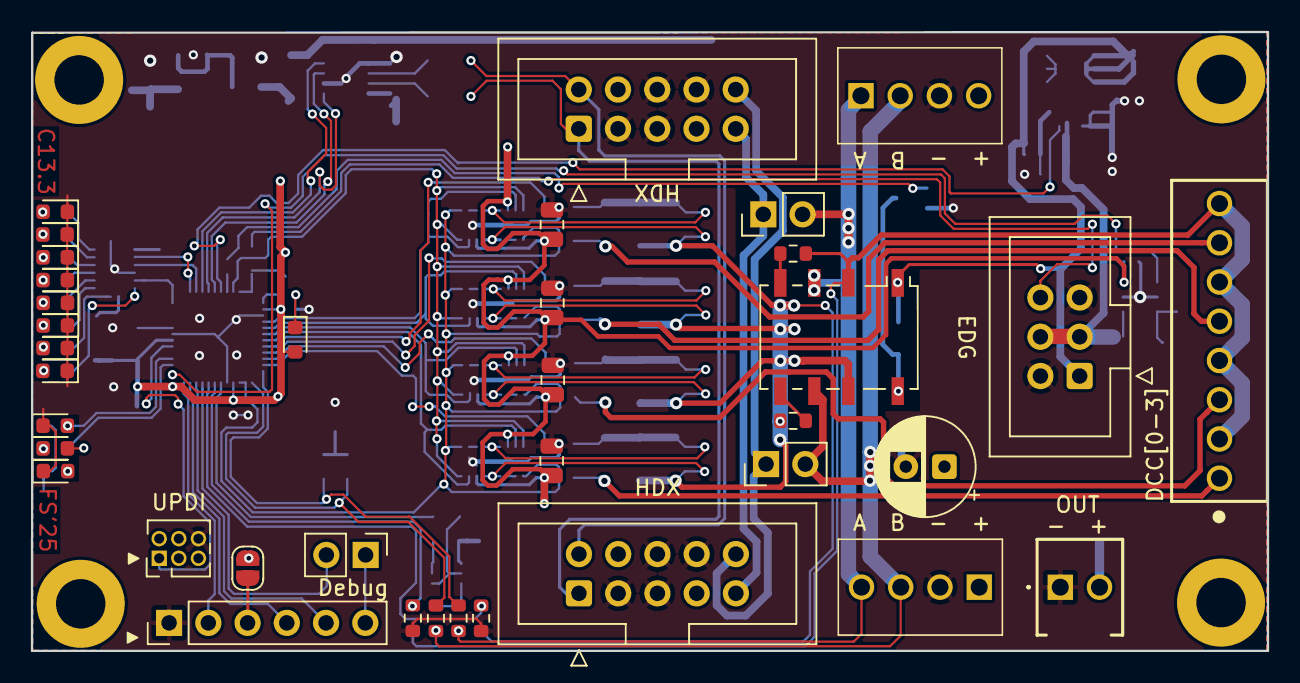
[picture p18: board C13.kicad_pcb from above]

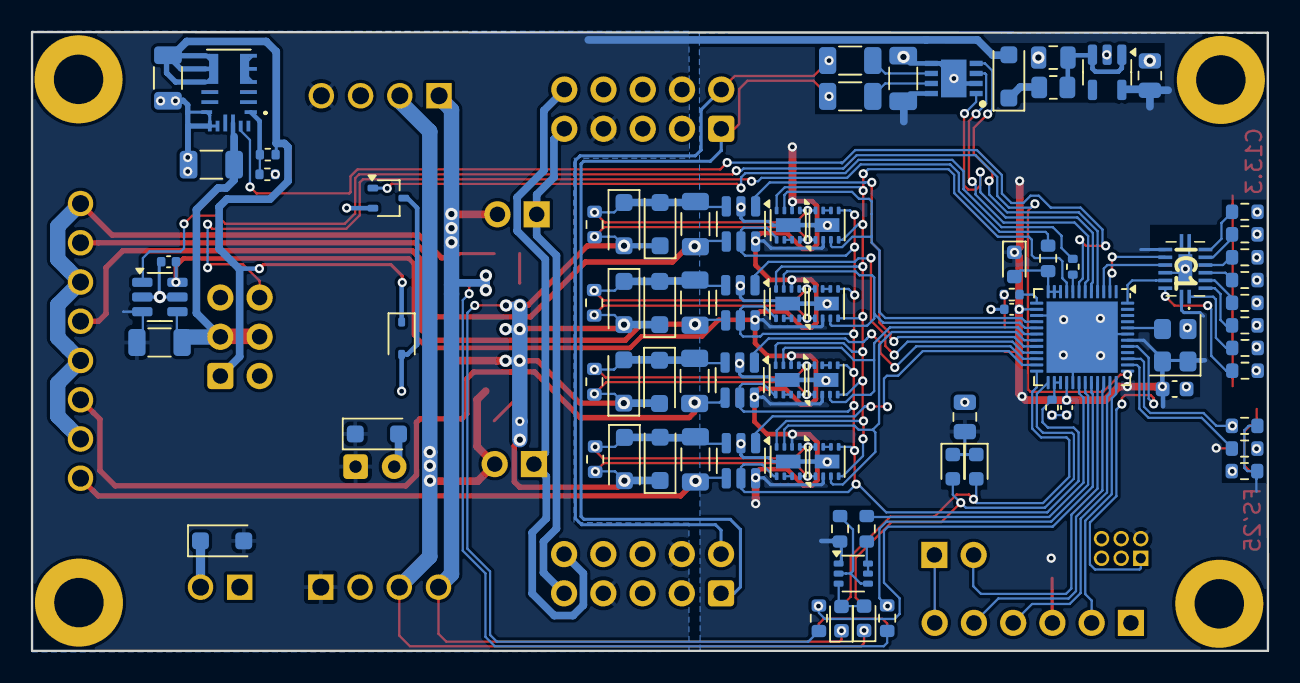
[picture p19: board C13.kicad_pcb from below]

Board: 2 copper layers, 80.0 x 40.1 mm, 122 parts (85 on the bottom side), 99 nets.

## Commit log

2025-10-13 mod: conversion to KiCad 9
    [C13.kicad_pcb, C13.kicad_sch, C13.sch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]
2025-11-18 mod: part #
    [C13.kicad_pcb, C13.kicad_sch, C13con.kicad_sch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]
2025-11-18 add: fuses document
2025-11-18 Add UPDI / Fuses section to README
    Added UPDI / Fuses section with fuse settings information.
